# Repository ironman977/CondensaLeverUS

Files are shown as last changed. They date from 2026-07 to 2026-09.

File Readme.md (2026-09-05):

# Whater Level Monitoring

With this project I want to monitor and alert me via telegram when the level of water in the condensation tank is too high. I live in appartament and I can't drain the condensation water anywhere other than into a container. When the tank is full the water go down to my neighbor and I don't want to fight for this :) 

# Hardware

I used a low cost WROOM 02 board based on ESP8266 with an on-board battery management system and battery holder for 18650 Li-ion battery [ArduinoForum](https://forum.arduino.cc/t/esp-wroom-02-with-battery-socket-does-it-need-extra-resistors-to-monitor-4-2v/483862)

To read the battery level I connected a 100k resistor from battery + pole to A0 pin, all the remaining stuff was did in firmware

To measure the tank levele I used an economic but effective ultrasound meter [HC-SR04](https://amzn.eu/d/0c41vQpR)

And finally the hose adapter to drain water into tank is a 3D object created to adapt the space available, more info at [ThingIverse](https://www.thingiverse.com/thing:7382079)

I had to solder RESET to GPIO16 to enable deep standby so I can use a battery for my circuit, WiFi is an enemy for batteries.

I created a 3d model for hose adapter for my condensation drainage into the tank, this allow the existances of hose and ultrasound meter [Condensa Level Monitor](./3dmodel/Condensa%20Level%20Monitor.png)

## Wiring WeMos to HC-SR04
```
WeMOS header                    HC-SR04 header

GND  --------------------------- GND
GND              +-------------- ECHO
5V ---------+    |  +----------- TRIG
3V3         +------------------- VCC
3V3              |  |
TX               |  |
RX               |  |
D8               |  |
D7 --------------+  |
D6 -----------------+
D5
D4
D3
D2
D1
A0
```

# Cloud to see data everywhere

I used ThingSpeak because is very simple ad I used it in the past for other small projects, my device is visible at [AllertaCondensa](https://thingspeak.mathworks.com/channels/3425868)

# Firmware

No more to say about it, simply read data about distance and find an average value, send it to ThingSpeak and evaluate if the level exceed the minimum distance for warning or for alert.
If in warning region (level between warning level and alert level) send once a message to Telegram chat_id you specify, if in alert region (below alert level) send every minute a message to Telegram

# Assembly

One picture say more than words

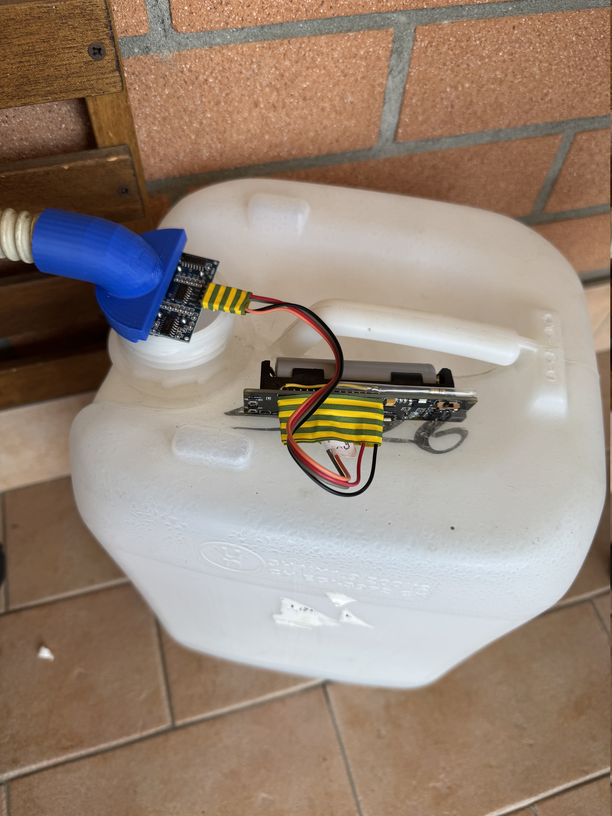
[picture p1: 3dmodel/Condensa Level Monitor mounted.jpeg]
Mounted


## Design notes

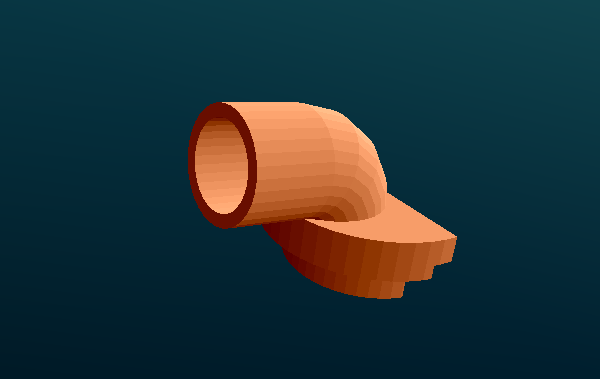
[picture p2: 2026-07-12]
3dmodel/Condensa Level Monitor.png

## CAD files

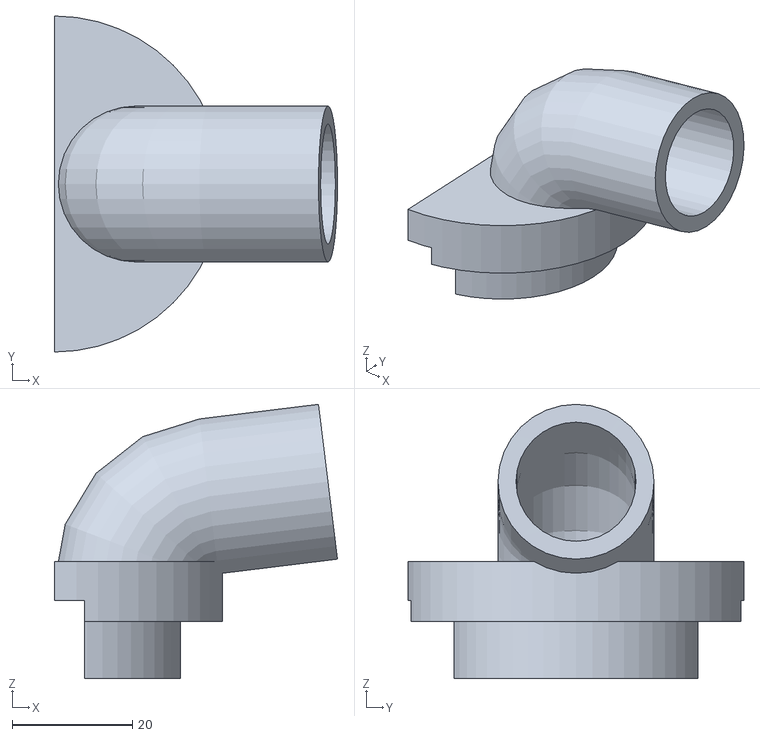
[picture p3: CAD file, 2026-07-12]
3dmodel/Condensa Level Monitor.stl
47.2 x 56.0 x 45.7

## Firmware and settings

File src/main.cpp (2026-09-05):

#include <Arduino.h>
#include <ESP8266WiFi.h>
#include <WiFiClientSecure.h>
#include <EEPROM.h>

#define trigPin D6
#define echoPin D7

#define wifi_ssid "WIFIHOME2"
#define wifi_password "8648002233"
#define DEEP_SLEEP_DURATION 15*60e6 // 15 minuti in microsecondi
#define SAMPLE_COUNT 5
#define TELEGRAM_BOT_TOKEN "7912486058:AAGefrulYuR3JXMkCqzW_XuEbhqTO3-0vZY"
#define CHAT_ID "5006717867"
#define WARNING_DISTANCE 60 // distanza in mm per inviare l'allarme
#define ALARM_DISTANCE 30 // distanza in mm per inviare l'allarme
#define HISTERESIS 15 // distanza in mm per evitare falsi allarmi

// salva in eeprom se il segnale di warning è stato inviato o meno
#define EEPROM_WARNING_SENT_ADDRESS 0
#define EEPROM_SIZE 4
bool warningSent = false;

void saveFlagIfChanged(bool value) {
  if (EEPROM.read(EEPROM_WARNING_SENT_ADDRESS) != (value ? 1 : 0)) {
    EEPROM.write(EEPROM_WARNING_SENT_ADDRESS, value ? 1 : 0);
    EEPROM.commit();
  }
}

bool readWarningSentFromEEPROM() {
  bool sent = EEPROM.read(EEPROM_WARNING_SENT_ADDRESS) == 1;
  EEPROM.end();
  return sent;
}


long durata, cm, mm;
bool sendWelcomeMessage = false;

long readBatteryVoltage() {
  int analogValue = analogRead(A0);
  float voltage = (float)analogValue * 0.0041016; // Converti il valore analogico in tensione VREF=1V e risoluzione 10 bit (1024 livelli)
  return voltage * 1000; // Restituisci la tensione in millivolt
}

// Connette il modulo alla rete WiFi come ts_client (station)
void connectWiFi() {
  Serial.println();
  Serial.print("Connessione a ");
  Serial.println(wifi_ssid);

  WiFi.mode(WIFI_STA);
  WiFi.begin(wifi_ssid, wifi_password);

  unsigned long startAttempt = millis();
  while (WiFi.status() != WL_CONNECTED && millis() - startAttempt < 15000) {
      delay(500);
      yield();
      Serial.print(".");
  }
  Serial.println();

  if (WiFi.status() == WL_CONNECTED) {
    Serial.print("WiFi connesso, IP: ");
    Serial.println(WiFi.localIP());
  } else {
    Serial.println("Connessione WiFi fallita");
  }
}

void setup() {
  Serial.begin(115200);
  EEPROM.begin(EEPROM_SIZE);
  warningSent = readWarningSentFromEEPROM();
  pinMode(trigPin, OUTPUT);
  pinMode(echoPin, INPUT);
  pinMode(A0, INPUT);

  rst_info *resetInfo = ESP.getResetInfoPtr();

  if (resetInfo->reason == REASON_DEEP_SLEEP_AWAKE) {
    Serial.println("Ripristino da deep sleep");
    sendWelcomeMessage = false;
  } else {
    // Power-on, reset esterno o crash: prima accensione "vera"
    Serial.println("Accensione dispositivo");
    sendWelcomeMessage = true;
  }

  connectWiFi();
}

int misuraDurata() {
  digitalWrite(trigPin, LOW);
  delayMicroseconds(2);

  digitalWrite(trigPin, HIGH);
  delayMicroseconds(10);

  digitalWrite(trigPin, LOW);

  return pulseIn(echoPin, HIGH, 30000);
}

void sendTelegramMessage(const String& message) {
  WiFiClientSecure telegram_client;
  telegram_client.setInsecure();
  telegram_client.setTimeout(3000);

  if (telegram_client.connect("api.telegram.org", 443)) {
    String path = "/bot" + String(TELEGRAM_BOT_TOKEN) + "/sendMessage";
    String body = "chat_id=" + String(CHAT_ID) + "&text=" + message;
    telegram_client.print(String("POST ") + path + " HTTP/1.1\r\n" +
                          "Host: api.telegram.org\r\n" +
                          "Content-Type: application/x-www-form-urlencoded\r\n" +
                          "Content-Length: " + String(body.length()) + "\r\n" +
                          "Connection: close\r\n\r\n" + body);
    delay(100);
    while(telegram_client.available()) {
      String line = telegram_client.readStringUntil('\n');
      Serial.println(line);
    }
    telegram_client.stop();
  }
}

void loop()
{
  if (WiFi.status() != WL_CONNECTED) {
    Serial.println("WiFi non connesso, tentativo di riconnessione...");
    connectWiFi();
    yield();
  }

  // Misura la distanza 3 volte e calcola la media scartando la misura più alta e quella più bassa
  long misure[SAMPLE_COUNT];
  int index = 0;
  while (index < SAMPLE_COUNT) {
    long misura = misuraDurata();
    if (misura > 0) {
      misure[index] = misura;
      index++;
    }
    delay(50);
  }
  // calcola la media scartando la misura più alta e quella più bassa
  long somma = 0;
  long min = misure[0];
  long max = misure[0];
  for (int i = 0; i < SAMPLE_COUNT; i++) {
    somma += misure[i];
    if (misure[i] < min) {
      min = misure[i];
    }
    if (misure[i] > max) {
      max = misure[i];
    }
  }
  somma = somma - min - max;
  long durata = somma / (SAMPLE_COUNT - 2); // media delle misure rimanenti
 

  long cm = durata / 58;
  long mm = durata / 5.8;
  long batteryVoltage = readBatteryVoltage();
  


  Serial.print("Cm = ");
  Serial.println(cm);
  Serial.print("Mm = ");
  Serial.println(mm);
  Serial.print("Battery Voltage (mV) = ");
  Serial.println(batteryVoltage);

  if (sendWelcomeMessage) {
    String welcomeMessage = "Sistema di monitoraggio della distanza attivo. Distanza attuale: " + String(mm) + " mm, Tensione batteria: " + String(batteryVoltage) + " mV. " +
    "Invio dati a ThingSpeak e monitoraggio allarmi attivo. Letture ogni " + String(DEEP_SLEEP_DURATION / 60000 / 1000) + " minuti. " +
    " Soglia di warning: " + String(WARNING_DISTANCE) + " mm, soglia di allarme: " + String(ALARM_DISTANCE) + " mm." +
    " Histeresi: " + String(HISTERESIS) + " mm. Indirizzo IP del dispositivo: " + WiFi.localIP().toString();
    sendTelegramMessage(welcomeMessage);
    sendWelcomeMessage = false;
  }

  WiFiClient ts_client;
  WiFiClientSecure telegram_client;
  telegram_client.setInsecure();
  telegram_client.setTimeout(3000);
  ts_client.setTimeout(3000);

  if (ts_client.connect("api.thingspeak.com", 80)) {
      String postStr = "api_key=2BZSTXSJHG3YMU11&field1=";
      postStr += String(cm);
      postStr += "&field2=";
      postStr += String(mm);
      postStr += "&field3=";
      postStr += String(batteryVoltage);
      postStr += "\r\n\r\n";

      ts_client.print("POST /update HTTP/1.1\r\n");
      ts_client.print("Host: api.thingspeak.com\r\n");
      ts_client.print("Connection: close\r\n");
      ts_client.print("Content-Type: application/x-www-form-urlencoded\r\n");
      ts_client.print("Content-Length: ");
      ts_client.print(postStr.length());
      ts_client.print("\r\n\r\n");
      ts_client.print(postStr);
      delay(100);

      while(ts_client.available()) {
          String line = ts_client.readStringUntil('\n');
          Serial.println(line);
      }      
      ts_client.stop();

      Serial.println("Dati inviati");
  }

  // Controlla se la distanza è inferiore alla soglia di warning o di allarme e invia un messaggio su Telegram se necessario
  if (mm < (WARNING_DISTANCE) && mm > (ALARM_DISTANCE)) {
    if (!warningSent) {
      if (telegram_client.connect("api.telegram.org", 443)) {
        String message = "WARNING: distanza inferiore a " + String(WARNING_DISTANCE) + " mm!";
        String path = "/bot" + String(TELEGRAM_BOT_TOKEN) + "/sendMessage";
        String body = "chat_id=" + String(CHAT_ID) + "&text=" + message;
        telegram_client.print(String("POST ") + path + " HTTP/1.1\r\n" +
                              "Host: api.telegram.org\r\n" +
                              "Content-Type: application/x-www-form-urlencoded\r\n" +
                              "Content-Length: " + String(body.length()) + "\r\n" +
                              "Connection: close\r\n\r\n" + body);
        delay(100);
        while(telegram_client.available()) {
          String line = telegram_client.readStringUntil('\n');
          Serial.println(line);
        }
        telegram_client.stop();
        warningSent = true;
        saveFlagIfChanged(warningSent);
        Serial.println("Messaggio di warning inviato e stato salvato in EEPROM");
      }
    } else {
      Serial.println("Messaggio di warning già inviato, non invio nuovamente");
    }
  } else if (mm > (ALARM_DISTANCE + HISTERESIS)) {
    warningSent = false;
    saveFlagIfChanged(warningSent);
    Serial.println("Distanza superiore alla soglia di warning, stato di warning resettato e salvato in EEPROM");
  }
  // Controlla se la distanza è inferiore alla soglia di allarme e invia un messaggio su Telegram se necessario senza memorizzare lo stato di warning
  if (mm < (ALARM_DISTANCE)) {
      String message = "ALARM: distanza inferiore a " + String(ALARM_DISTANCE) + " mm!";
      sendTelegramMessage(message);
      Serial.println("Messaggio di allarme inviato");
  }
  
  Serial.println("vado in deep sleep");
  ESP.deepSleep(DEEP_SLEEP_DURATION); // 15 minuti (il parametro è in microsecondi)

  yield();  

}

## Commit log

2026-09-05 Migliorata doc, aumentato il tempo di deep sleep a 15 minuti, aggiunto messaggio di benvenuto al primo avvio del sistema.
2026-09-05 Ora il messaggio di benvenuto viene inviato solo una volta all'avvio del dispositivo, invece che ad ogni ciclo del loop principale.
